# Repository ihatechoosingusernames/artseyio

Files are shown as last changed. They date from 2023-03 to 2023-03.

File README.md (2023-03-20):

# artseyio
Hardware for an [ARTSEYIO layout](https://artsey.io/) single hand keyboard. The controller is a [CH552G](https://raw.githubusercontent.com/WeActStudio/WeActStudio.CH552CoreBoard/master/Datasheet/CH552DS1_en.PDF) and connects via USB-C.

The firmware requires [SDCC](https://sdcc.sourceforge.net/) and is based on an [excellent project by Wagiminator](https://github.com/wagiminator/CH552-USB-Knob).

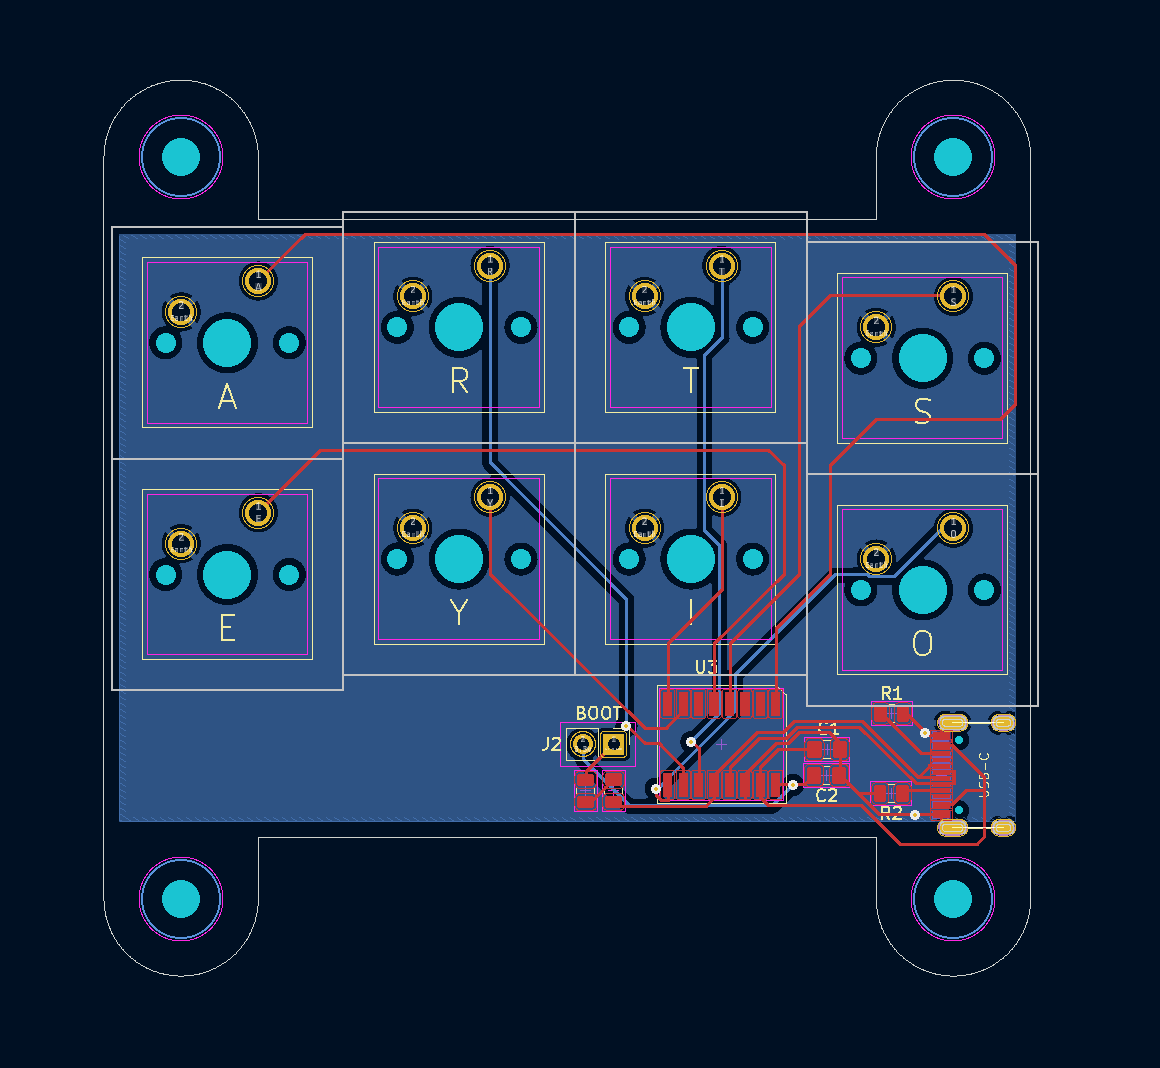
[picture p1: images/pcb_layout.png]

The v1.1 layout.

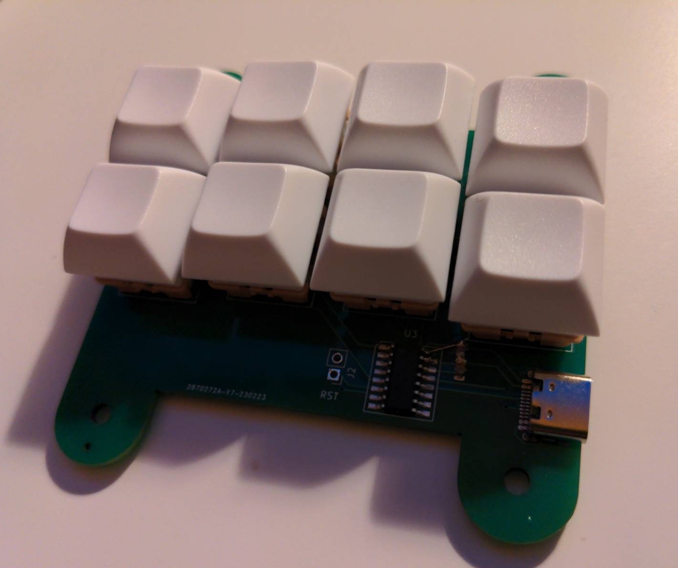
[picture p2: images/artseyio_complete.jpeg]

A completed v1.0 board.

### Flashing
To compile the software, install sdcc and python3 and pyusb with pip, following the instructions from the [Wagiminator repo.](https://github.com/wagiminator/CH552-USB-Knob)

To flash, power up the board while shorting the BOOT jumper with tweezers or a piece of solder. Release the short once the device is plugged in, it should be in boot mode. Run `make flash` in the artseyio-firmware directory, and the board should be programmed.

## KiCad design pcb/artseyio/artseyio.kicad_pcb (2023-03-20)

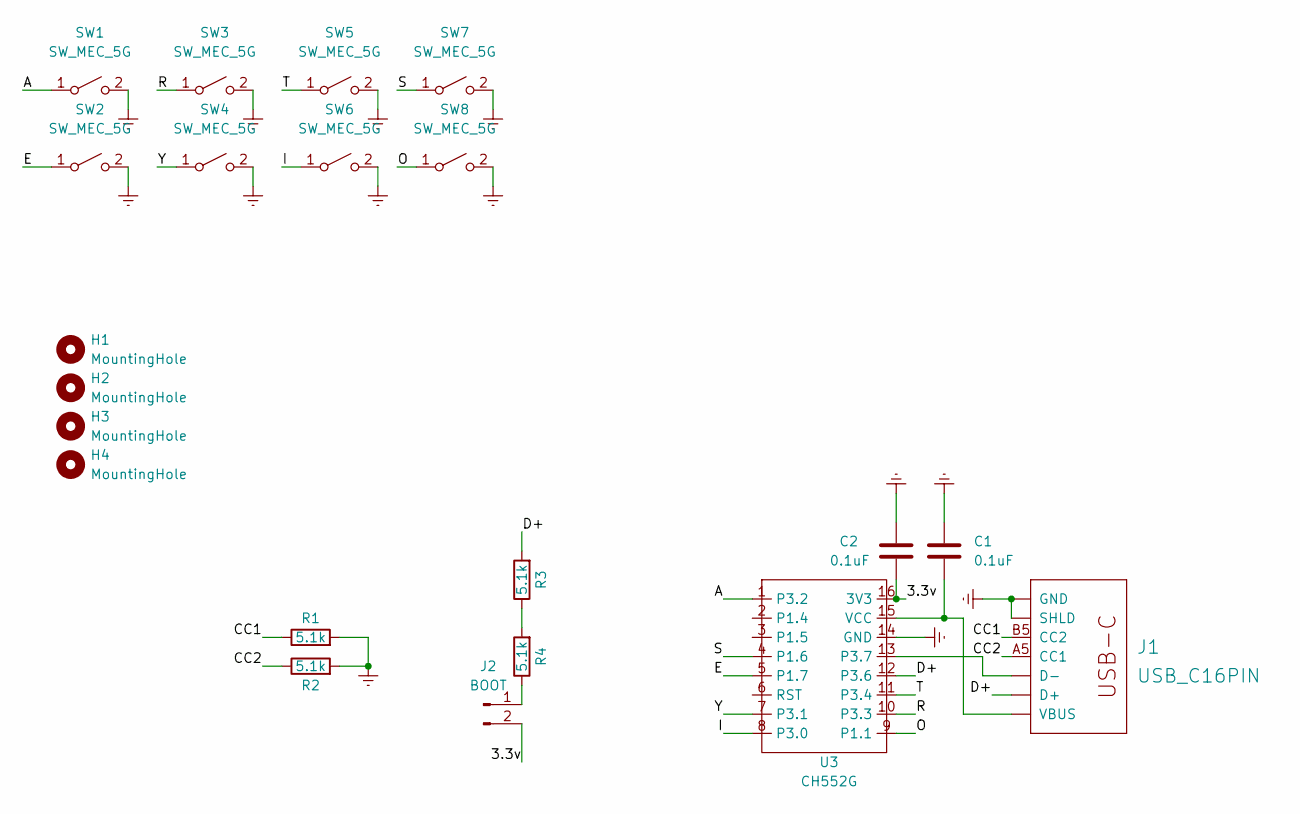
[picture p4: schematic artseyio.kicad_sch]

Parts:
C1, C2: 0.1uF; C_0805_2012Metric_Pad1.18x1.45mm_HandSolder
H1, H2, H3, H4: MountingHole; MountingHole_3.2mm_M3
J1: USB_C16PIN; USB-C-COM-15111
J2: BOOT; PinHeader_1x02_P2.54mm_Vertical
R1, R2, R3, R4: 5.1k; R_0805_2012Metric
SW1, SW2, SW3, SW4, SW5, SW6, SW7, SW8: SW_MEC_5G; SW_Cherry_MX_1.00u_PCB
U3: CH552G

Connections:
/3.3v: C2.2, J2.2, U3.16 (3V3)
/A: SW1.1 (A), U3.1 (P3.2)
/CC1: J1.B5 (CC2), R1.1
/CC2: J1.A5 (CC1), R2.1
/D+: J1.A6 (D+), J1.B6 (D+), R3.2, U3.12 (P3.6)
/E: SW2.1 (A), U3.5 (P1.7)
/I: SW6.1 (A), U3.8 (P3.0)
/O: SW8.1 (A), U3.9 (P1.1)
/R: SW3.1 (A), U3.10 (P3.3)
/S: SW7.1 (A), U3.4 (P1.6)
/T: SW5.1 (A), U3.11 (P3.4)
/Y: SW4.1 (A), U3.7 (P3.1)
Earth: C1.1, C2.1, J1.GND, J1.GND2 (GND), J1.SHLD1 (SHLD), J1.SHLD2 (SHLD), J1.SHLD3 (SHLD), J1.SHLD4 (SHLD), J1.SHLD5 (SHLD), J1.SHLD6 (SHLD), J1.SHLD7 (SHLD), J1.SHLD8 (SHLD), R1.2, R2.2, SW1.2 (B), SW2.2 (B), SW3.2 (B), SW4.2 (B), SW5.2 (B), SW6.2 (B), SW7.2 (B), SW8.2 (B), U3.14 (GND)
unnamed: C1.2, J1.VBUS1 (VBUS), J1.VBUS2 (VBUS), U3.15 (VCC)
unnamed: J1.A7 (D-), J1.B7 (D-), U3.13 (P3.7)
unnamed: J2.1, R4.1
unnamed: R3.1, R4.2

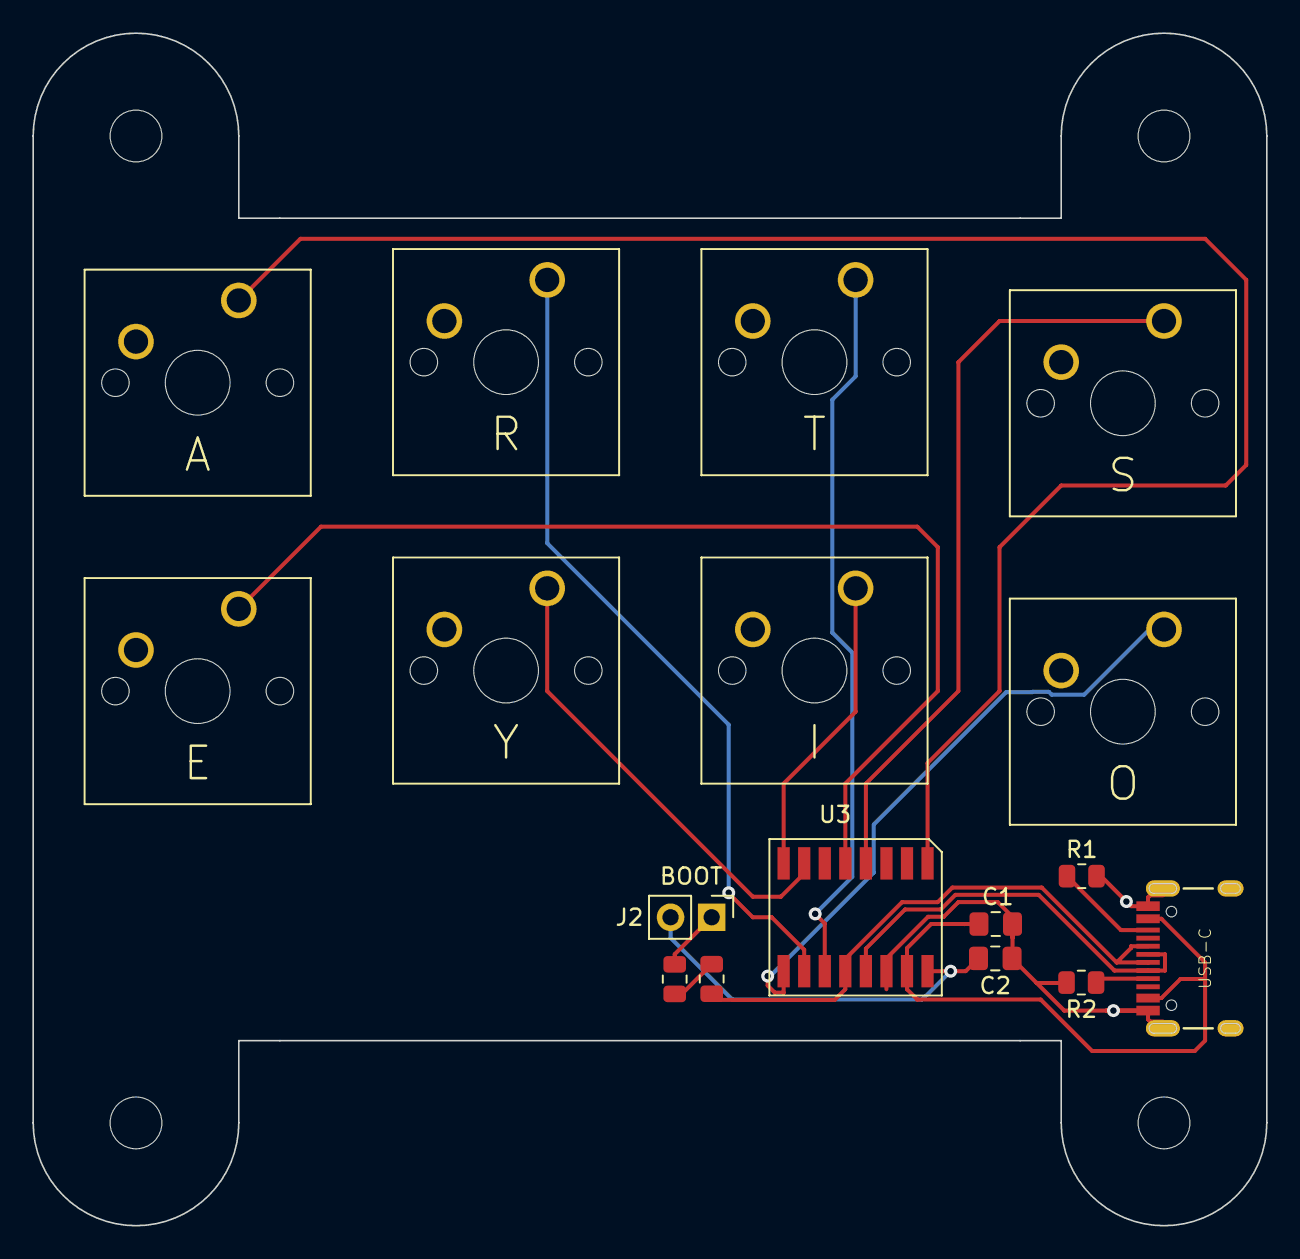
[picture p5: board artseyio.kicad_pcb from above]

Board: 2 copper layers, 76.2 x 73.7 mm, 21 parts (0 on the bottom side), 17 nets.

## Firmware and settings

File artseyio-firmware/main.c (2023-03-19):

// ===================================================================================
// Project:   USB Rotary Encoder for CH551, CH552 and CH554
// Version:   v1.0
// Year:      2023
// Author:    Stefan Wagner
// Github:    https://github.com/wagiminator
// EasyEDA:   https://easyeda.com/wagiminator
// License:   http://creativecommons.org/licenses/by-sa/3.0/
// ===================================================================================
//
// Description:
// ------------
// Implements the ARTSEYIO format in a keyboard
//
// References:
// -----------
// - Blinkinlabs: https://github.com/Blinkinlabs/ch554_sdcc
// - Deqing Sun: https://github.com/DeqingSun/ch55xduino
// - Ralph Doncaster: https://github.com/nerdralph/ch554_sdcc
// - WCH Nanjing Qinheng Microelectronics: http://wch.cn
// - ATtiny85 TinyKnob: https://github.com/wagiminator/ATtiny85-TinyKnob
//
// Compilation Instructions:
// -------------------------
// - Chip:  CH551, CH552 or CH554
// - Clock: min. 12 MHz internal
// - Adjust the firmware parameters in include/config.h if necessary.
// - Make sure SDCC toolchain and Python3 with PyUSB is installed.
// - Press BOOT button on the board and keep it pressed while connecting it via USB
//   with your PC.
// - Run 'make flash'.
//
// Operating Instructions:
// -----------------------
// - Connect the board via USB to your PC. It should be detected as a HID device.
// - Turn the rotary endoder to increase/decrease volume.
// - Press rotary encoder button to mute.


// ===================================================================================
// Libraries, Definitions and Macros
// ===================================================================================

// Libraries
#include <config.h>                       // user configurations
#include <system.h>                       // system functions
#include <delay.h>                        // delay functions
#include <gpio.h>                         // GPIO functions
#include <usb_kbd.h>                      // USB HID consumer keyboard functions
#include <artseyio.h>                     // ARTSEYIO Layer logic

#define READ_PIN_BIT(PIN, BIT) ((PIN_read(PIN) ? 0x00 : 0x01) << BIT)

// Prototypes for used interrupts
void USB_interrupt(void);
void USB_ISR(void) __interrupt(INT_NO_USB) {
  USB_interrupt();
}

// ===================================================================================
// Main Function
// ===================================================================================
void main(void) {

  // Setup
  CLK_config();                           // configure system clock
  DLY_ms(5);                              // wait for clock to settle
  KBD_init();                             // init USB HID keyboard
  WDT_start();                            // start watchdog timer

  uint8_t input_key_state;

  PIN_input_PU(PIN_A);                    // Set input pins with pullups
  PIN_input_PU(PIN_R);
  PIN_input_PU(PIN_T);
  PIN_input_PU(PIN_S);
  PIN_input_PU(PIN_E);
  PIN_input_PU(PIN_Y);
  PIN_input_PU(PIN_I);
  PIN_input_PU(PIN_O);

  // Loop
  while(1) {
    DLY_ms(SCAN_DELAY);                    // a little delay (latch + debounce)
    WDT_reset();                           // reset watchdog

    input_key_state = 0x00;                // reset key state
    
    // Read GPIOS connected to keys
    input_key_state |= READ_PIN_BIT(PIN_A, 7);
    input_key_state |= READ_PIN_BIT(PIN_R, 6);
    input_key_state |= READ_PIN_BIT(PIN_T, 5);
    input_key_state |= READ_PIN_BIT(PIN_S, 4);
    input_key_state |= READ_PIN_BIT(PIN_E, 3);
    input_key_state |= READ_PIN_BIT(PIN_Y, 2);
    input_key_state |= READ_PIN_BIT(PIN_I, 1);
    input_key_state |= READ_PIN_BIT(PIN_O, 0);

    // Update key states
    set_key_state(input_key_state);
  }
}

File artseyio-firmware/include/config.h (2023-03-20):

// ===================================================================================
// User Configurations for CH552E USB Rotary Encoder
// ===================================================================================

#pragma once

// Pin definitions
#define PIN_A P32
#define PIN_R P33
#define PIN_T P34
#define PIN_S P16
#define PIN_E P17
#define PIN_Y P31
#define PIN_I P30
#define PIN_O P11

// USB device descriptor
#define USB_VENDOR_ID       0x0000    // VID
#define USB_PRODUCT_ID      0x0000    // PID
#define USB_DEVICE_VERSION  0x0100    // v1.0 (BCD-format)

// USB configuration descriptor
#define USB_MAX_POWER_mA    50        // max power in mA 

// USB descriptor strings
#define MANUFACTURER_STR    'A','n','d','r','e','w','\'','s',' ','k','b'
#define PRODUCT_STR         'A','R','T','S','E','Y','I','O'
#define SERIAL_STR          'C','H','5','5','2','x','H','I','D'
#define INTERFACE_STR       'H','I','D','-','K','e','y','b','o','a','r','d'

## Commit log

2023-02-18 Added hardware design and layout.
    [artseyio.kicad_pcb, artseyio.kicad_sch]
2023-02-18 Updated readme with pcb layout.
2023-02-19 Updated schematic to include a CH552 with builtin USB-C port.
    [artseyio.kicad_pcb, artseyio.kicad_sch]
2023-02-19 Updated PCB Layout image
2023-02-20 Updated the footprint shape and updated the ESP32 pinout.
    [artseyio.kicad_pcb, artseyio.kicad_sch]
2023-02-20 Updated reversed switches, rearranged CH552 to reduce vias and USB track length.
    [artseyio.kicad_pcb]
2023-02-20 Added updated gerbers for release v0.2
2023-02-21 Added reset jumpers for CH552G
    [artseyio.kicad_pcb, artseyio.kicad_sch]
2023-02-22 Updated to remove RP2040-Zero and ESP32.
    [artseyio.kicad_pcb, artseyio.kicad_sch]
2023-03-14 Added in some missing features to make programming it easier, handle CC lines on USB-C.
    [artseyio.kicad_pcb, artseyio.kicad_sch]
2023-03-19 Fixed hold layer implementation and tap code reset bug.
    [main.c]
2023-03-20 Filled out v1.1 design with boot jumper and correct cc line pulldowns.
    [artseyio.kicad_pcb, artseyio.kicad_sch]
2023-03-20 Fixed image, generated gerbers.
2023-03-20 Updated readme with flashing instructions.
    [artseyio.kicad_pcb]
